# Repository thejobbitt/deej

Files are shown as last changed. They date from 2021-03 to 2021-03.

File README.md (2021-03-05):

# Super Compact Monitor Mount (SCMM)

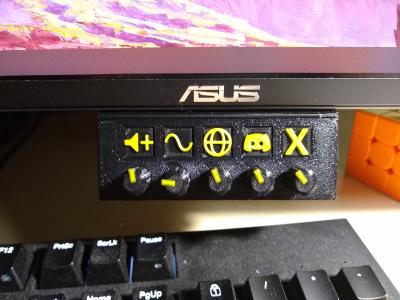
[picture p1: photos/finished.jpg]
SCMM Build


## Table of contents

- [Parts and Pieces](#parts-and-pieces)
- [Electronic Assembly](#electronics-assembly)
- [Case](#case)
- [Info about the deej project](#info-about-the-deej-project)

## Parts and Pieces

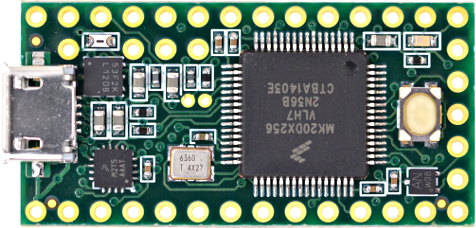
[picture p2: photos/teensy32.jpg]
Teensy


Teensy is my favorite platform, works very well for keyboards and very full featured for the price. If you want to save some money on the build go with the recommended Arduino Nano, Pro Micro or Uno.
https://www.pjrc.com/store/teensy32.html

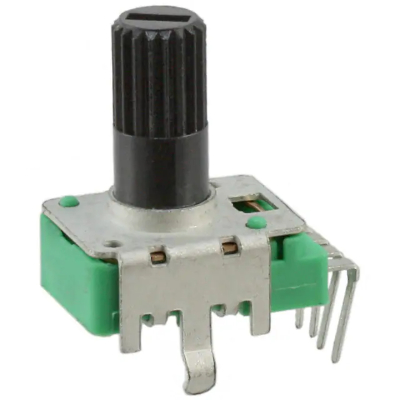
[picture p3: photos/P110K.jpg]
Pot


Small in size, high in quality.
https://www.digikey.com/en/products/detail/tt-electronics-bi/P110KH-0Y20BR10K/2408865

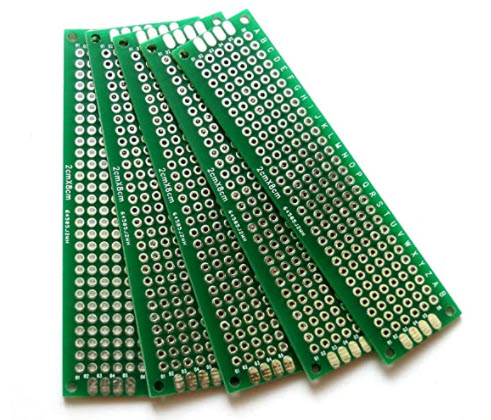
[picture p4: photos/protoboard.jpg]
Proto Board


20 x 80mm, nothing fancy here, always good to have some laying around.
https://www.amazon.com/gp/product/B012YZ2Q3W/ref=ppx_yo_dt_b_search_asin_title?ie=UTF8&psc=1

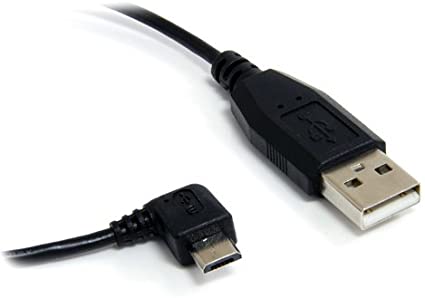
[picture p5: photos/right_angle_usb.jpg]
USB


Right angle micro USB, connect directly into the monitor if supported.
https://www.amazon.com/gp/product/B003YKX6WC/ref=ppx_yo_dt_b_asin_title_o01_s00?ie=UTF8&psc=1

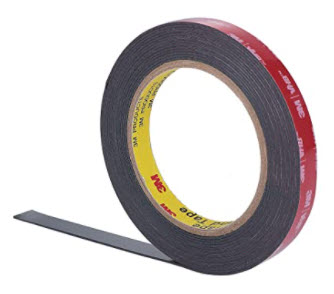
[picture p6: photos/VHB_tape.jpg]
VHB


Tape to attach to monitor. 
https://www.amazon.com/gp/product/B07K4SFP4D/ref=ppx_yo_dt_b_search_asin_title?ie=UTF8&psc=1

M3 Bolt

m3 x 8mm Screw to hold the electronics in the housing.
https://www.mcmaster.com/91292A112/

## Electronics Assembly

SCMM is built on a proto board using 10k potentiometers and a Teensy 3.2 Micro. (SCMM was built with parts I had, I suggest you use the Teensy LC or the Arduino Nano, Pro Micro or Uno if you are ordering new.)

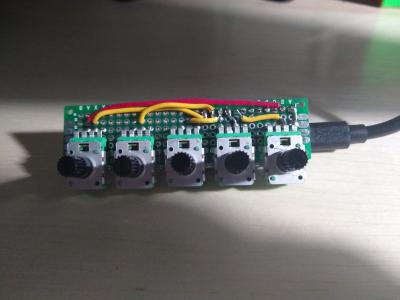
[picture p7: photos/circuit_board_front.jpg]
Front
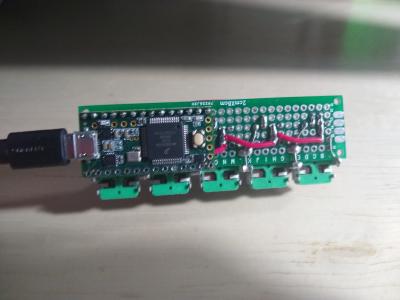
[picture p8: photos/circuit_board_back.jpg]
Back
 

Soild wire used for all connections. There is a bit of assembly order. Make the ground and +3.3v connections (bus) first, then figure out the wiper wires to Teensy AIO pins. Also connect the pots metal housing to ground and solder them all together to increase mechanical structure. If you are using the Teensy LC, you have to use the 3.3v, 5v will kill the board. Teensy 3.2 will be fine with either 3.3 or 5v, for this project I used 3.3v.

## Case

Both Fusion 360 and STEP files are in the CAD folder

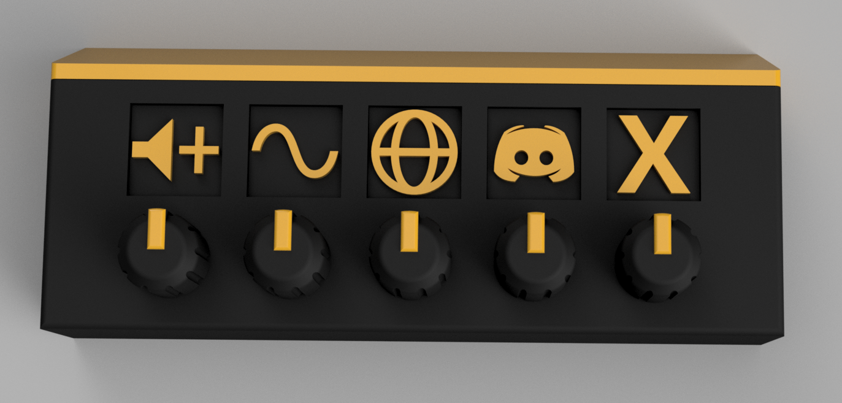
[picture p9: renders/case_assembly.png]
Case Render


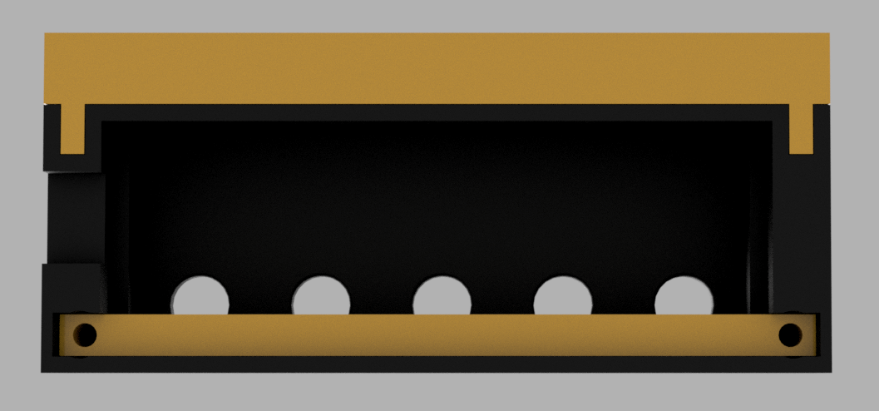
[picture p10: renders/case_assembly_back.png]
Case Render Back


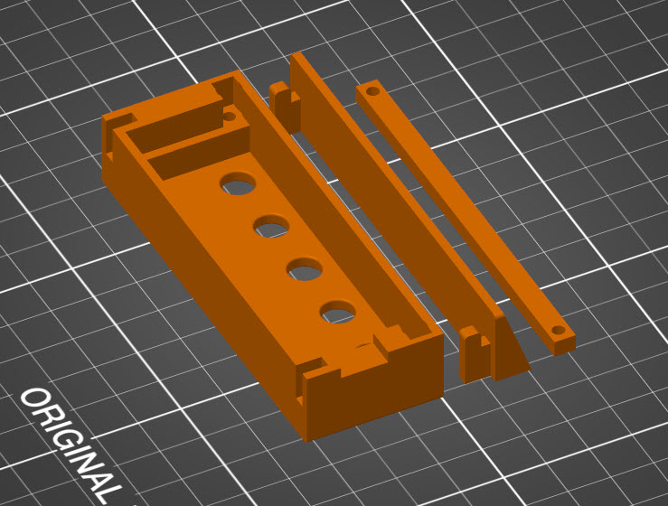
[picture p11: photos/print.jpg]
Print


All parts are designed with printing in mind and do not need any support. I used a Prusa i3 mk3s with Prusa Slicer, 0.2 layer height, PETG.

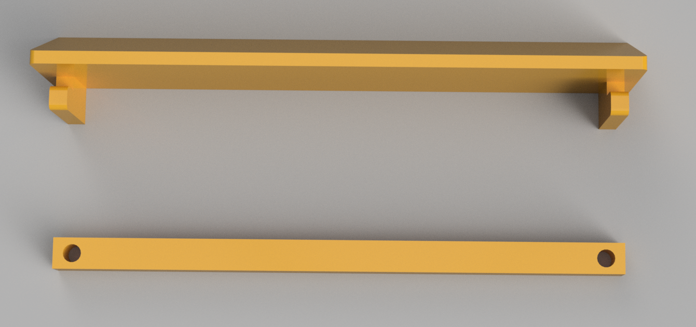
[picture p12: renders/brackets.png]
Brackets


The Upper Bracket is attached to the monitor with VHL tape. I used the 3M VBL 5952. The Lower Bracket uses two m3 x 8mm screws to hold the electronics in the housing.

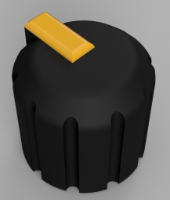
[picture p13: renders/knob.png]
Knob
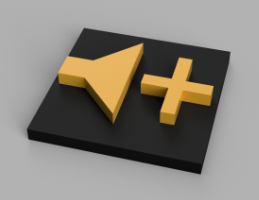
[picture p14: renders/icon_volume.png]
Icon
 

Both the knob and the icons are designed to print two colors using a single filament change.

## Info about the deej project

https://github.com/omriharel/deej

deej is an **open-source hardware volume mixer** for Windows and Linux PCs. It lets you use real-life sliders (like a DJ!) to **seamlessly control the volumes of different apps** (such as your music player, the game you're playing and your voice chat session) without having to stop what you're doing.

**Join the [deej Discord server](https://discord.gg/nf88NJu) if you need help or have any questions!**



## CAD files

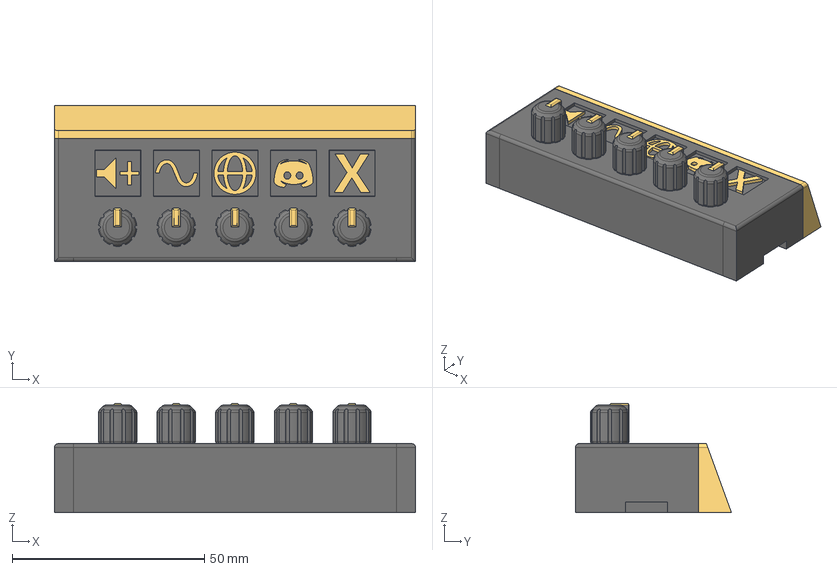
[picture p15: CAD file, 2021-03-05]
cad/case_assembly.step
94.0 x 40.7 x 28.5 mm
deej knob x 5
volume
system
www
discord
active

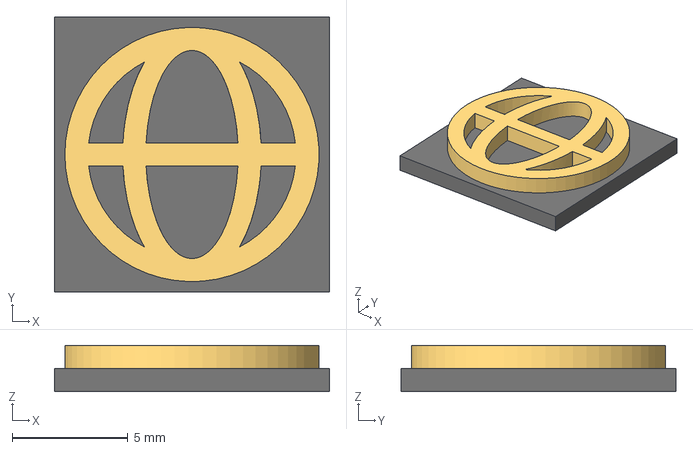
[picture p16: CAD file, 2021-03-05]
cad/icon_www.step
11.9 x 11.9 x 2.00 mm

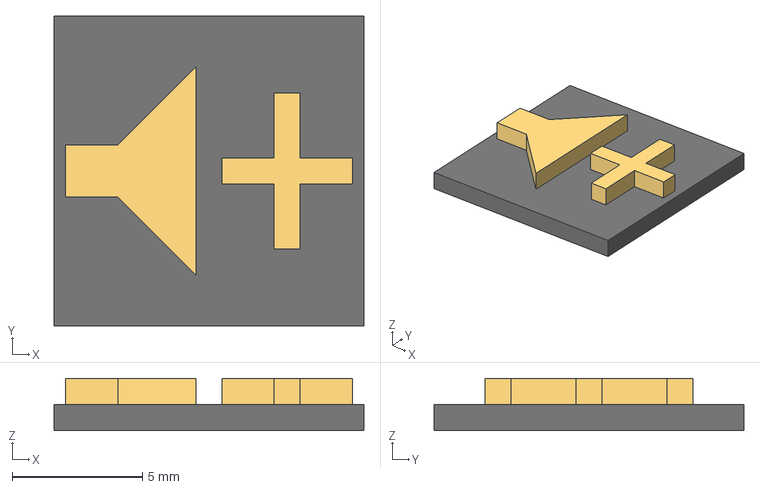
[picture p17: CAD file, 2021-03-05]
cad/icon_volume.step
11.9 x 11.9 x 2.00 mm

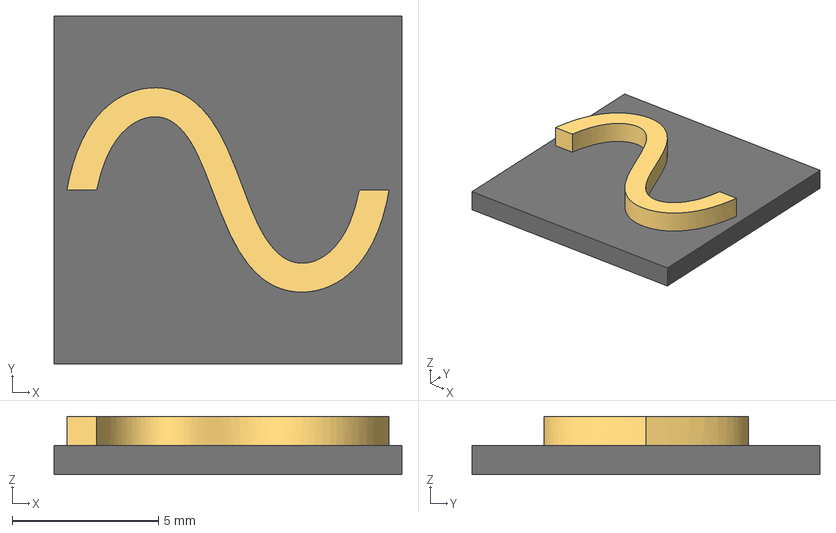
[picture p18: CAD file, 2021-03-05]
cad/icon_system.step
11.9 x 11.9 x 2.00 mm

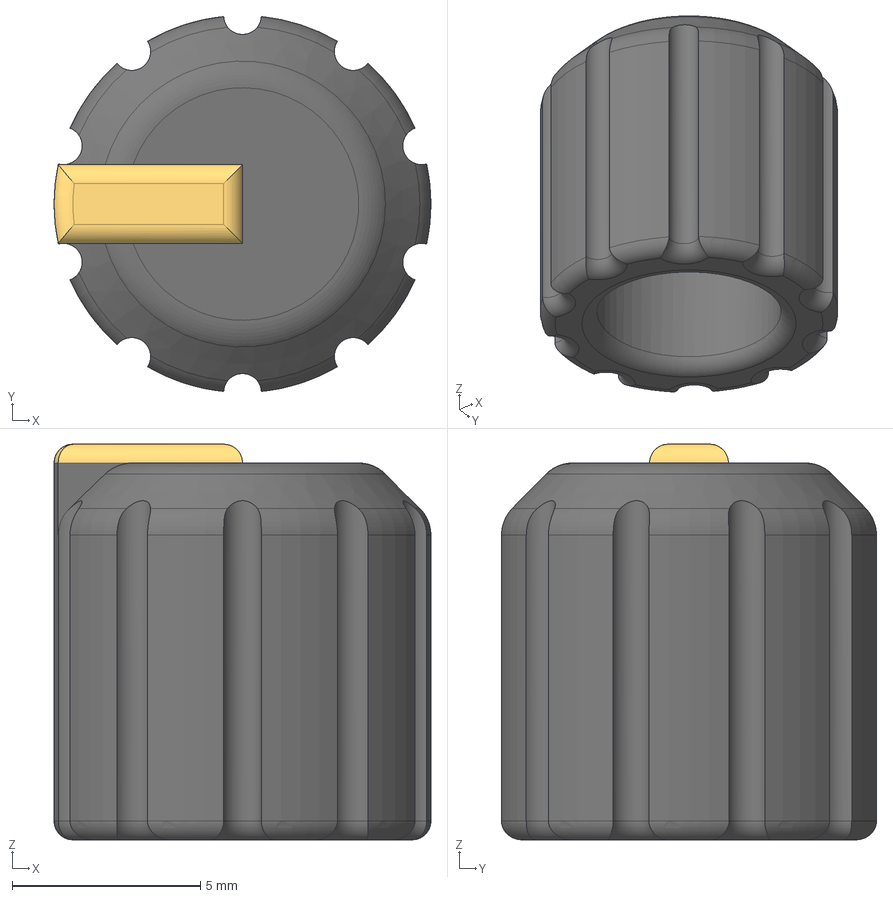
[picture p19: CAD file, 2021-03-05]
cad/knob.step
10.0 x 9.95 x 10.5 mm

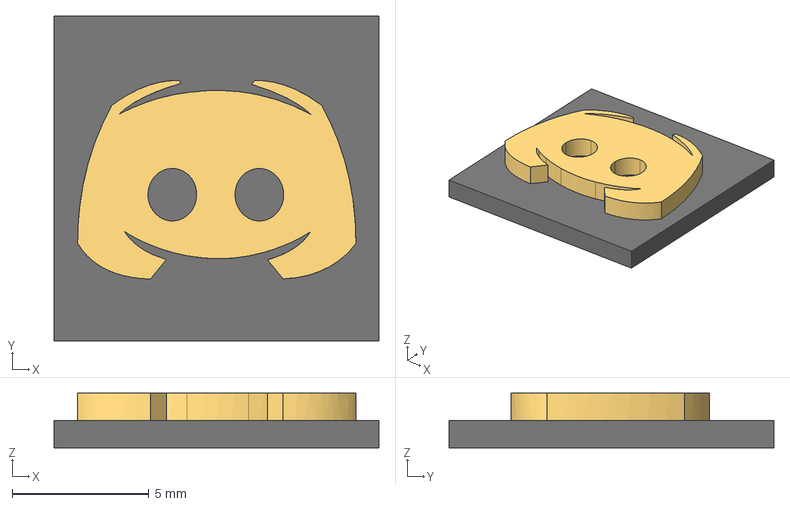
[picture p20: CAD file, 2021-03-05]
cad/icon_discord.step
11.9 x 11.9 x 2.00 mm

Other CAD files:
cad/icon_active.step
cad/cace_assembly.f3z
cad/icon_active.f3d
cad/icon_discord.f3d
cad/icon_system.f3d
cad/icon_volume.f3d
cad/icon_www.f3d
cad/knob.f3d
